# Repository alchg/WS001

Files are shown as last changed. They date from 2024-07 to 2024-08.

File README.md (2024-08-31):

# WS001  
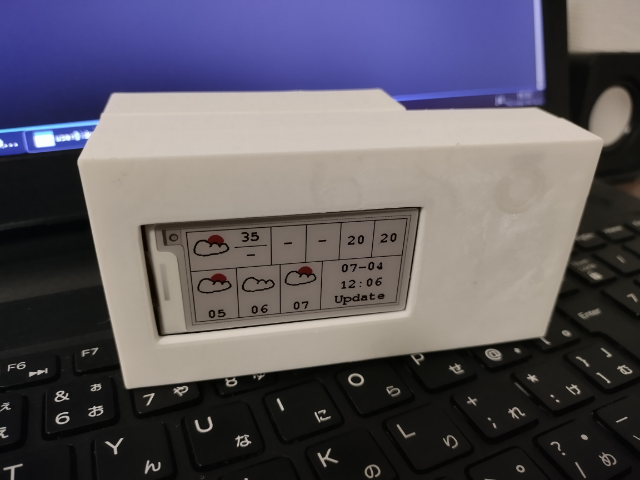
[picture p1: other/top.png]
Top Image
  
乾電池式電子ペーパーお天気ディスプレイのレポジトリです。  
作成マニュアルからプログラムやケースの３Ｄデータを含んでいます。  

# 仕様  
2.4Ghz WiFi（インターネットからの天気予報取得に必要）  
Bluetooth BLE（スマホから本機の初期設定する際に必要、LightBlueなどのBLE管理アプリが必要）  
気象庁の提供JSONデータによる全国天気予報表示  
一日４度の天気情報更新  
単３乾電池３本USB電源（有線USB電源も可能）  
連続動作３ヶ月以上（ニッケル水素充電池1950mAhによる）  

# 始め方  
最初のドキュメントは下記になります。  
ドキュメント\000はじめに.docx

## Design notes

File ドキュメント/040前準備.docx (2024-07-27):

Arduino IDEの準備（Arduino IDE 2.3.2を例とします）

- ボードマネージャーからesp32の2.0.6を導入します。

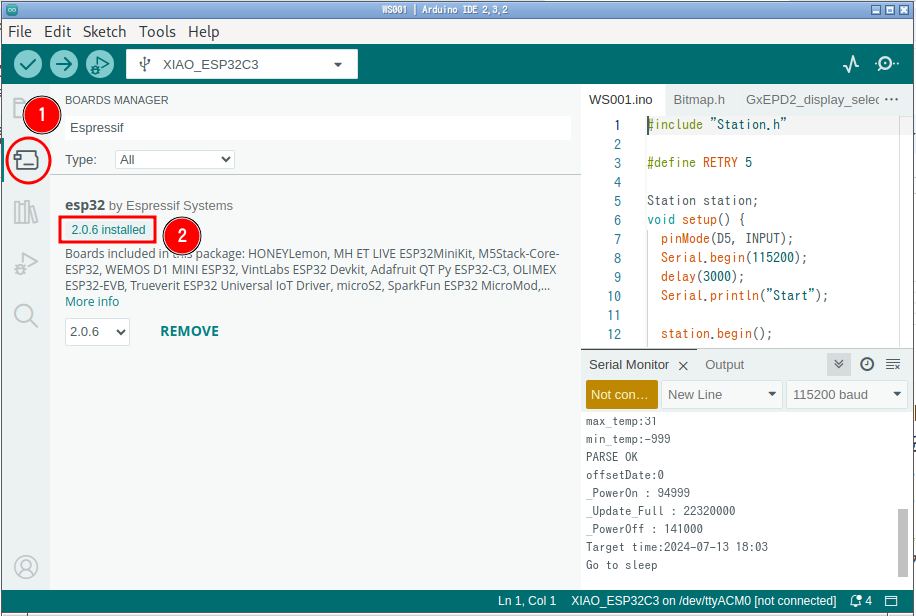
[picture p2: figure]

- ライブラリマネージャーからGxEPD2を導入します。

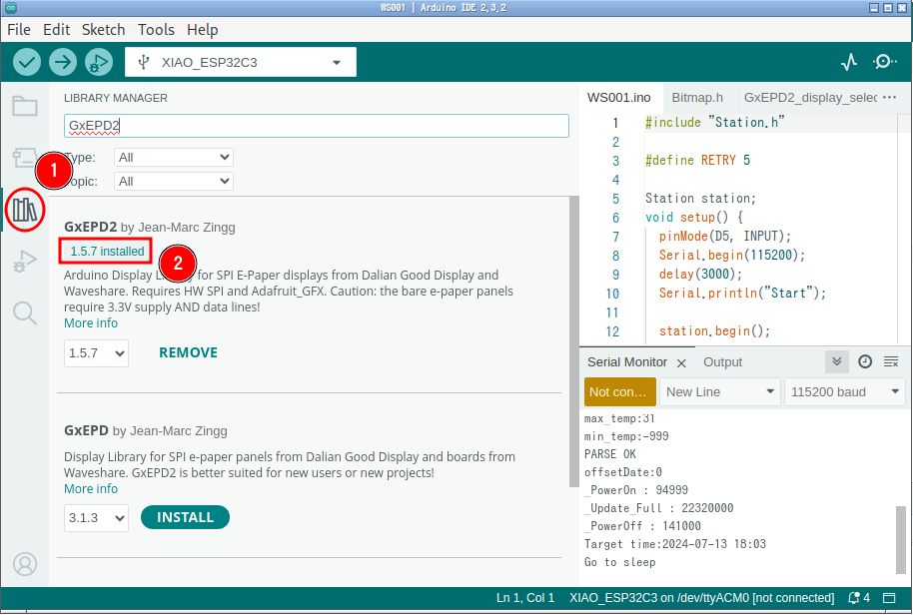
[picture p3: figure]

- ライブラリマネージャーからArduinoJsonを導入します。

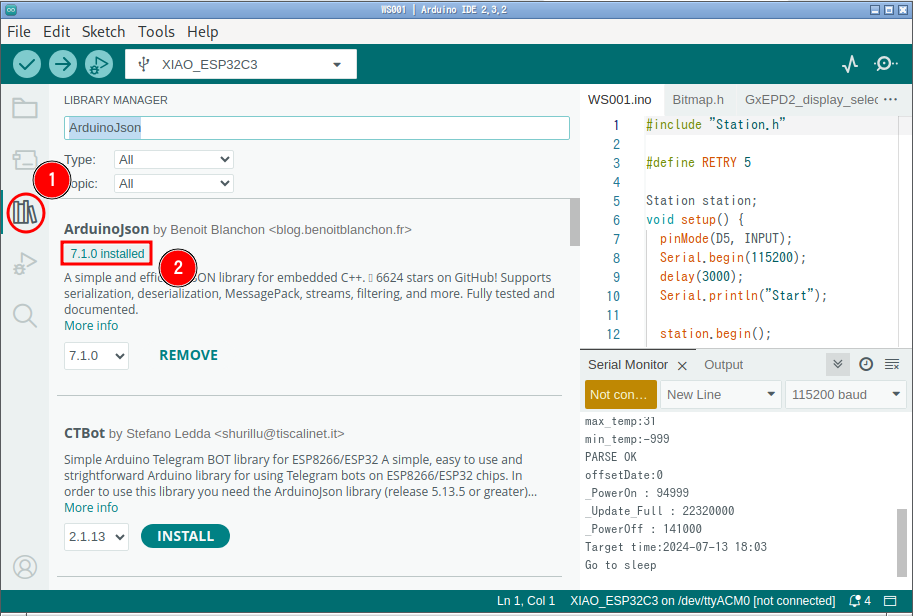
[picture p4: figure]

- プログラムのアップロードの設定は以下になります。赤枠を設定してください。

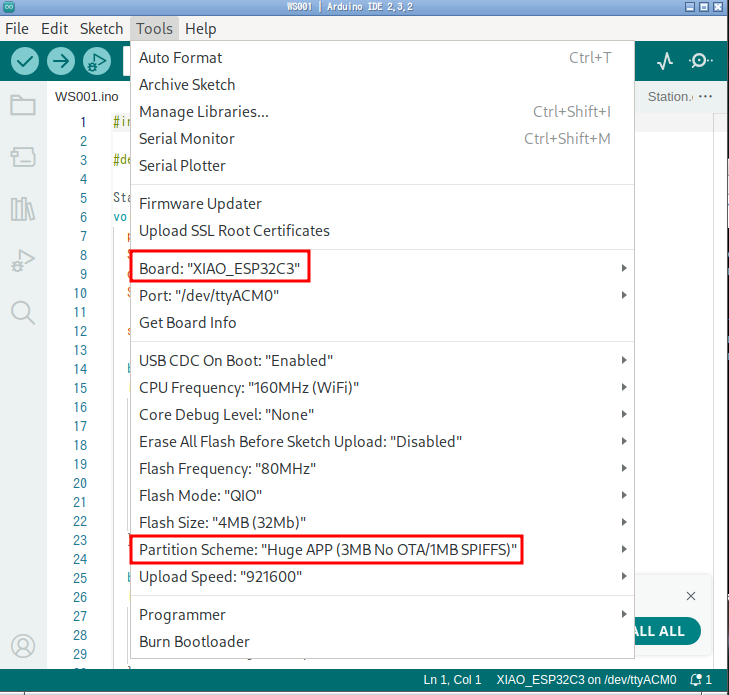
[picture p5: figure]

- この時点でXIAO ESP32 C3と接続して空プログラムのアップロードが可能であることを確認して置くことを推奨（Pythonやpyserialの導入や権限の設定など環境依存する場合があります）

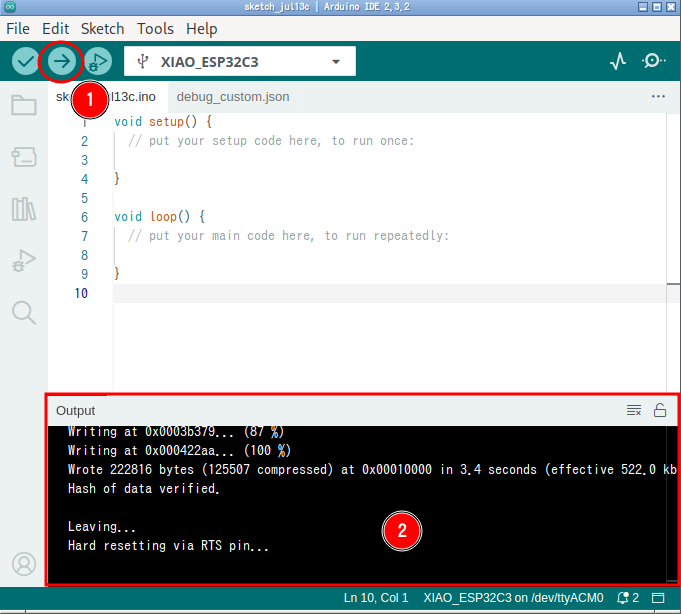
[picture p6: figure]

パーツの準備

- モジュールボックスと電池ボックスをセメダインABS用で接着します。配線用の穴の位置がずれないように注意して下さい。重しを乗せるかクランプ等で固定することを推奨します。（貼付け面に歪みが出ている場合は２つのパーツの貼り付け面を3Dプリンタのヒードベットで温めなおして押当てて調整することを推奨）

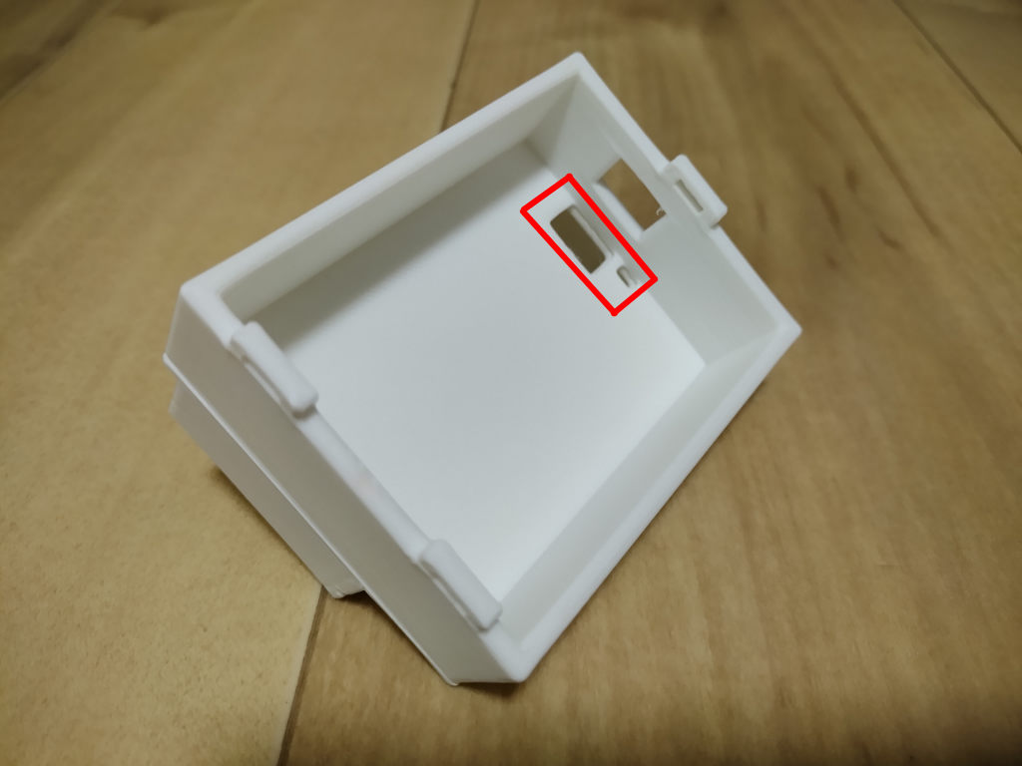
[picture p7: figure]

- Seeed Studio XIAO ESP32C3に7P×2のピンヘッダをハンダします。

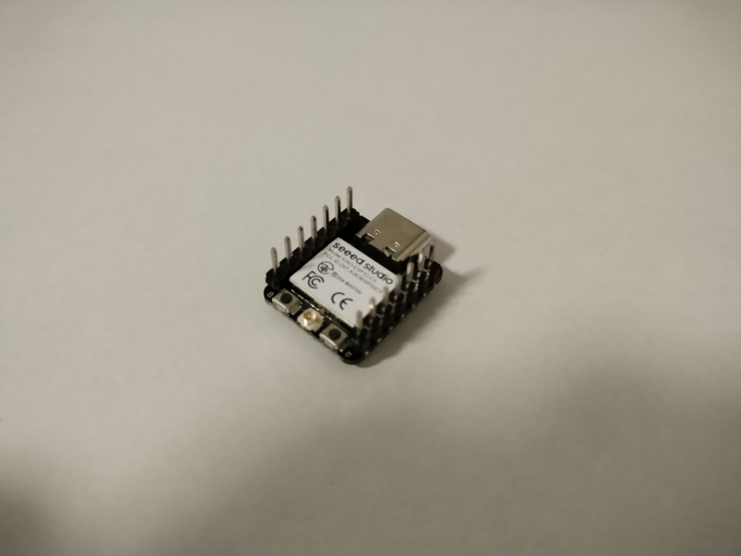
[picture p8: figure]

- TTP223に3P×1のピンヘッダをハンダします。

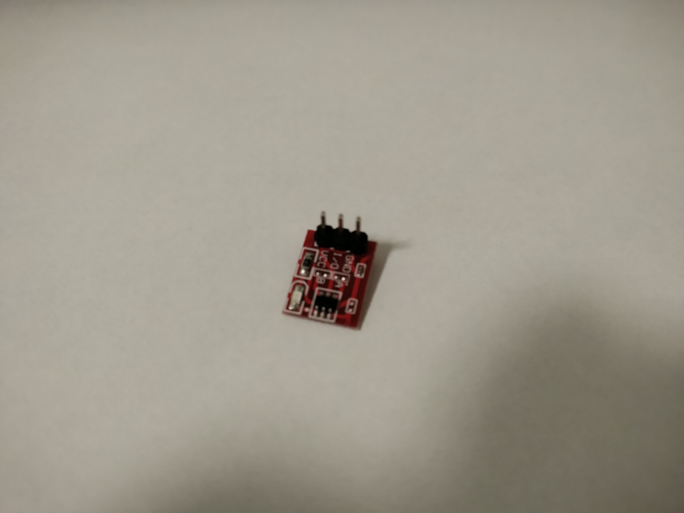
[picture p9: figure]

- MH-ET LIVE 2.13 REDに付属の真っ直ぐのピンヘッダをハンダします。

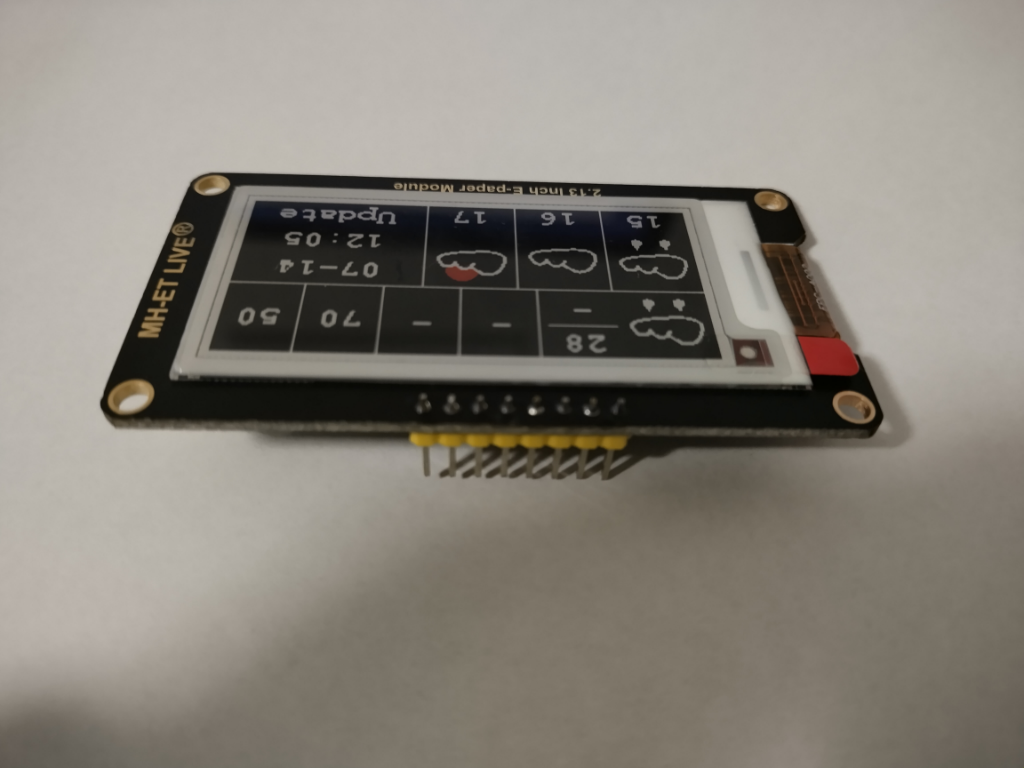
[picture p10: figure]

- 10cmと15cmメスーメスのジャンパピンを加工して分配ケーブルを作ります。ニッパー等で切断と被膜の除去を行い、絡めてハンダし、テープ等で絶縁処理します。赤と黒の２個作ります。

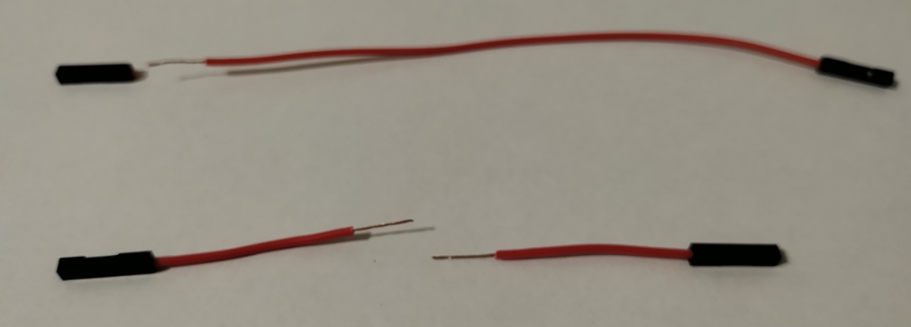
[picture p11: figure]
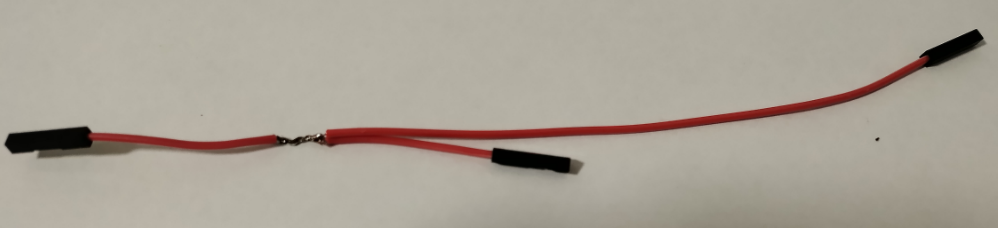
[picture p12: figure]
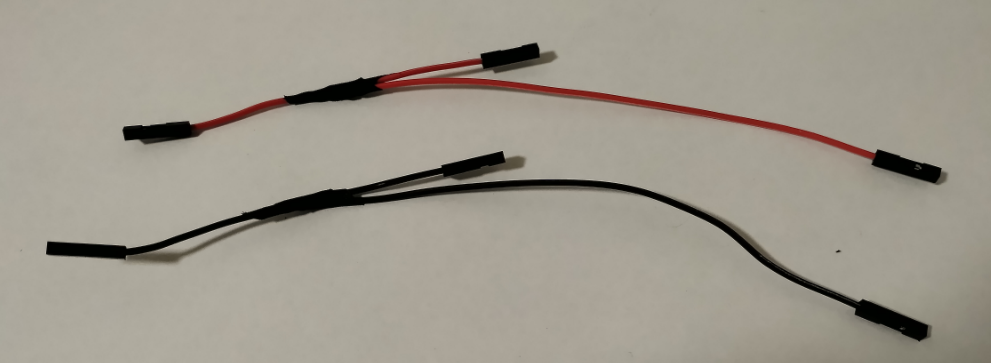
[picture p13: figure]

- 乾電池昇圧モジュールのLEDを除去します。LEDの両端を温めながらずらしていくと外せます。

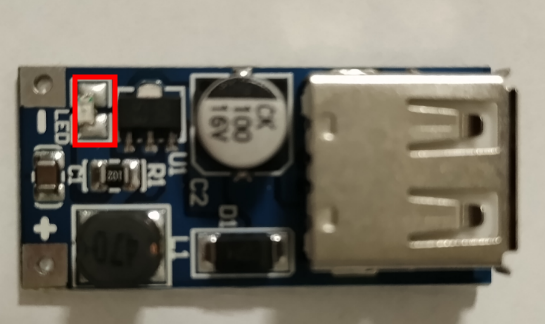
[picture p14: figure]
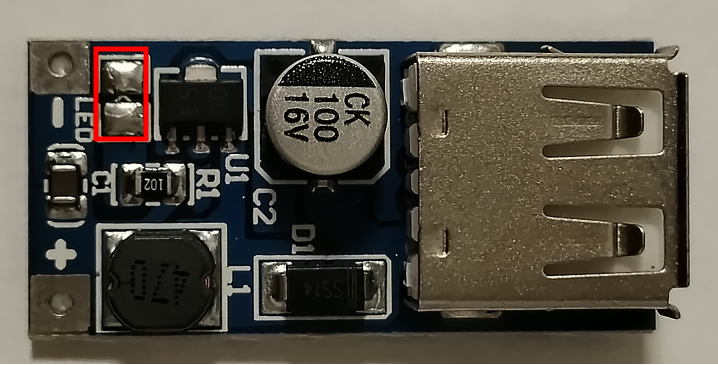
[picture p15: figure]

備考：必要な前準備は以上ですがブレッドボード等の電子パーツが既にある人は各部品の動作チェックを予め行っておくと良いでしょう。

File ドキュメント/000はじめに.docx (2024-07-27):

- はじめに

これはWS001-乾電池式電子ペーパーお天気ディスプレイのDIY向け手順書になります。

本プロジェクトは複雑な作業を減らすことを主要課題にしていますが、必要に応じてサーチエンジンによる情報検索等が必要になる場合があることを予め御了承願います。

機種依存になる3Dプリンタ印刷部分を除いた部分が、この組み立てマニュアルのメインパートになります。

3Dプリントに必要なモデルデータは本レポジトリに含まれることをここに明記しておきたいと思います。

また必要な手順や情報等は可能な限り含めていきますので続きのドキュメントを必要に応じてご覧ください。

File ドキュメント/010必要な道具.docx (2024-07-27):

必要な道具について記述します

- パソコンとUSB Type C通信ケーブル
  - 各種ソフトウェアを利用する為に必要です。ケーブルはファームウェアの書込みに使用します。
- スマートフォン（Bluetooth BLE）
  - WS001の初期設定にBluetooth BLE対応アプリの使用を必要とします。
- 3Dプリンタ及びその付属品
  - 熱溶解積層方式を想定しています。２万円台のプリンタで確認済みです。
- ニッパー
  - 電線の処理に使用します。ワイヤーストリッパーがある場合は推奨します。
- ビニールテープ
  - 絶縁処理に使用します。アセテート粘着テープがある場合は推奨します。
- はんだごてセット
  - ピンヘッダの接続などに使用します。複雑な事はしませんので安価な物で大丈夫ですが高性能品を使うと楽に作業できます。
- セメダインABS用
  - プラスチックパーツの接着に使用します。

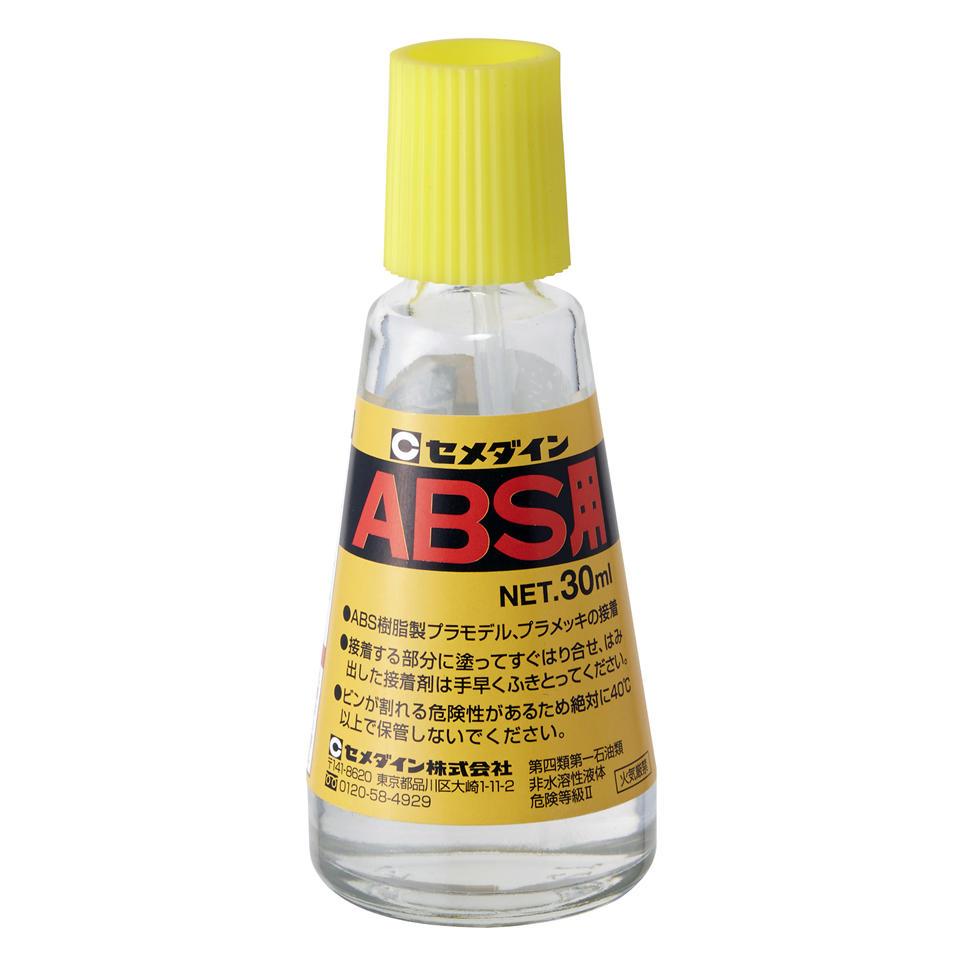
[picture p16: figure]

あると役に立つ可能性があるもの

- ルーター（電動工具）
  - ちょっとした加工やバリ取りなど幅広く活用できます。
- グルーガン
  - 固定に不安がある場合に活用できます。絶縁性もあります。
- クランプ
  - プラスチックパーツの接着など固定に活用できます。

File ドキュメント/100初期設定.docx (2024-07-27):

WS001の初期設定について記述します。Bluetooth BLE管理アプリが必要となります。例としてスマホアプリLightBlueを用いて記述します。

- 初回起動時、または電源ONから３秒以内に右上をタッチし続けると設定モードになります。

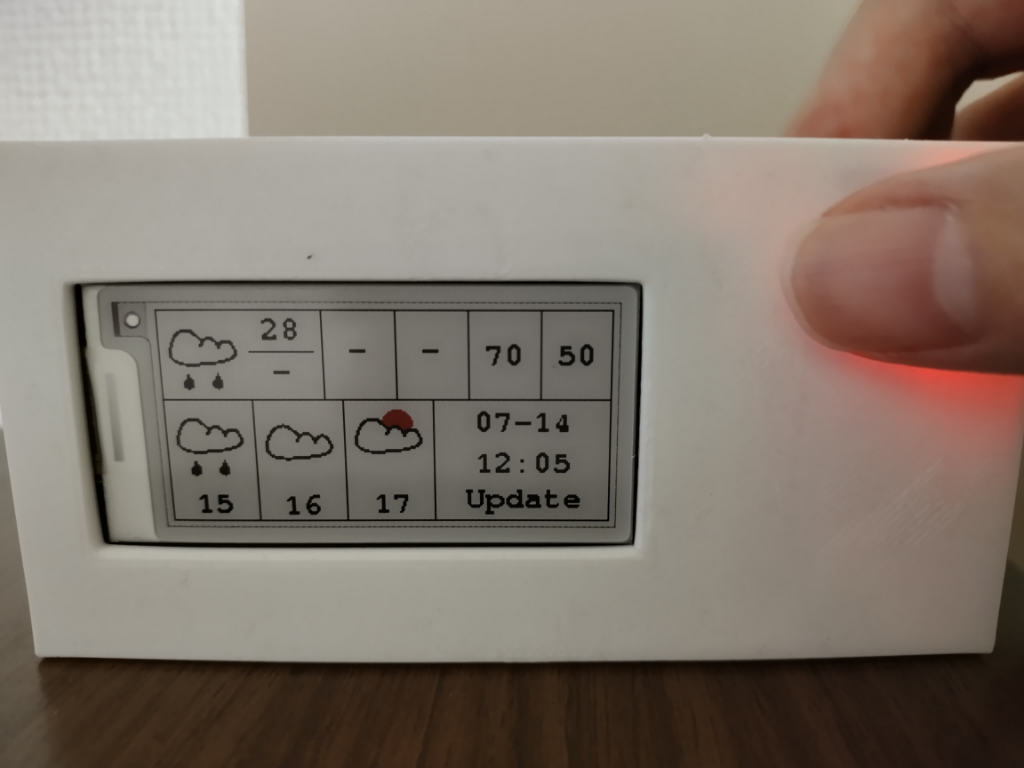
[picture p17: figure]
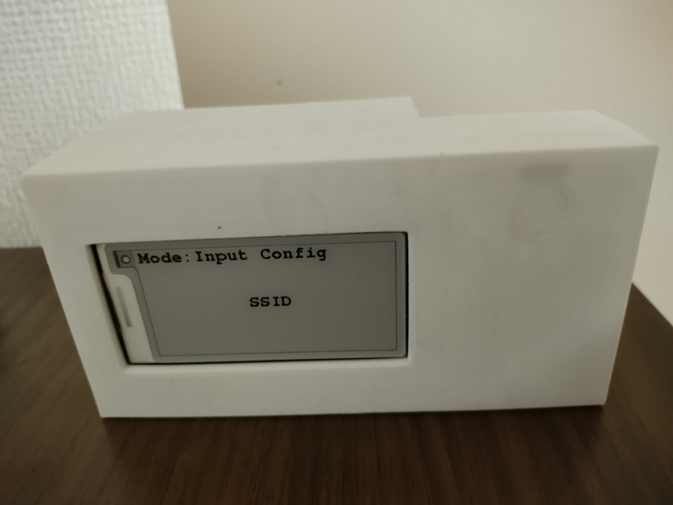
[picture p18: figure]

- スマホアプリLightBlueでWS001に接続します。

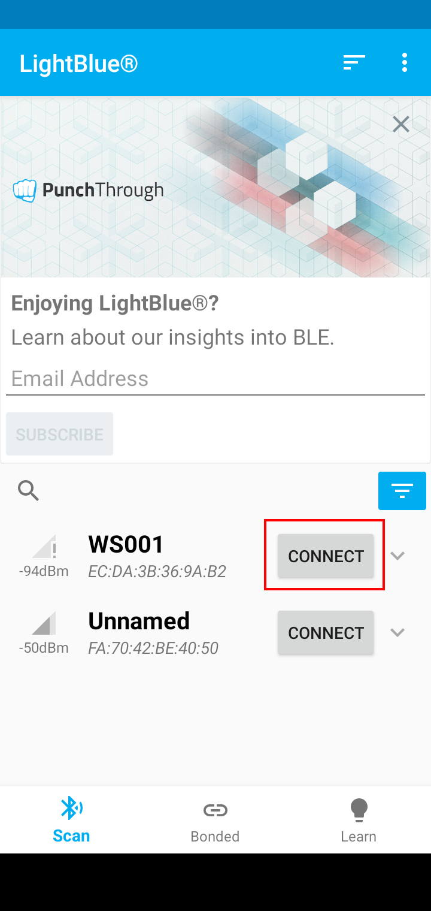
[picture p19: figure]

- WritableのUUIDを選択します。

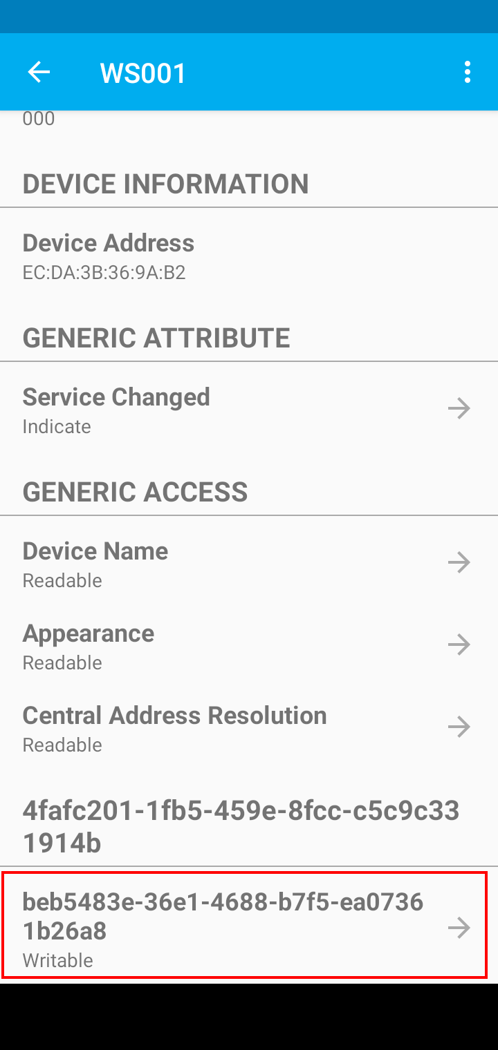
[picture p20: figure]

- UTF-8 Stringを選択してテキストを入力後にWRITEを選択するとデータを送信できます。最初はSSIDとパスワードを設定します。WS001の画面に従い設定して下さい。

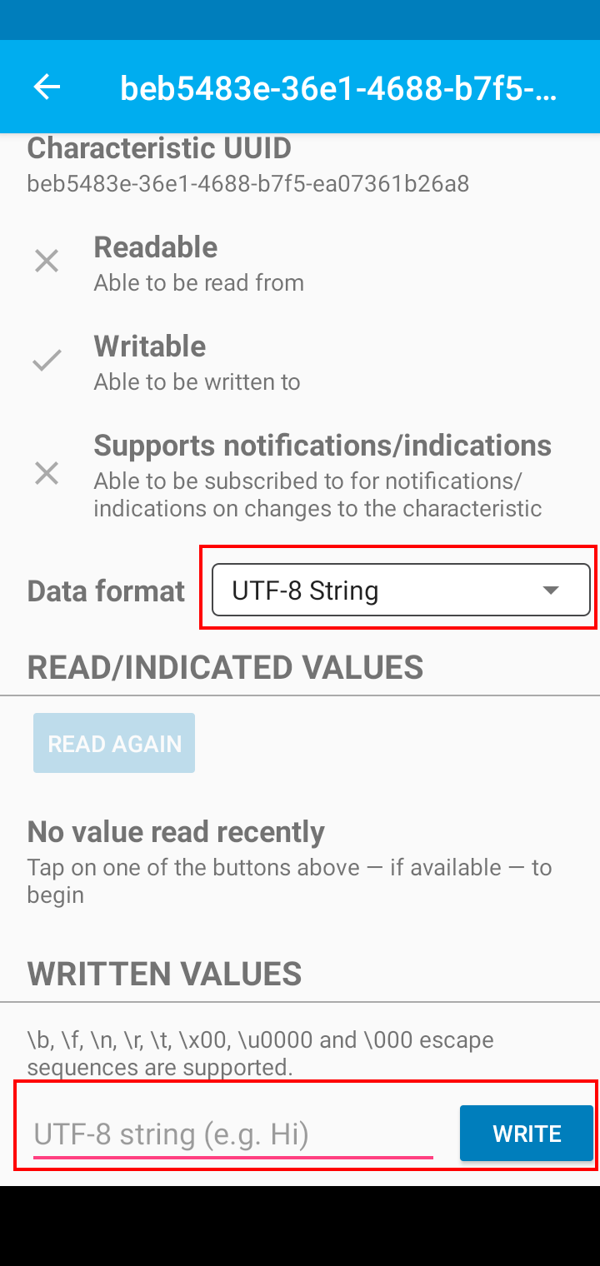
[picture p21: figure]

- WS001の画面に従い、前述の方法でエリアコードを設定していきます。101エリアコードから１行を選択し設定して下さい。
- 最後にダークモードを設定します。0で通常モード、1でダークモードです。

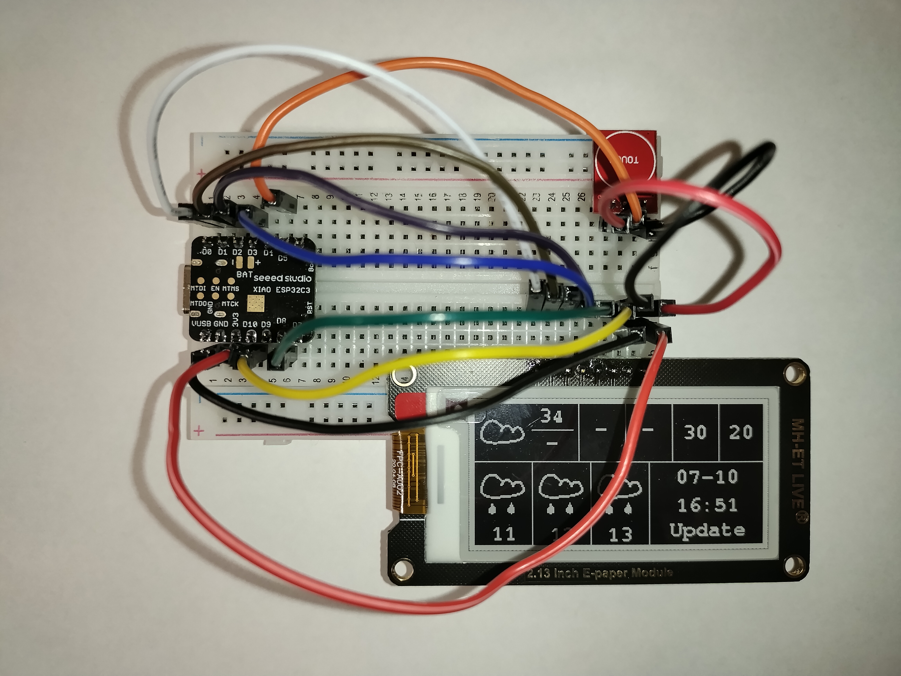
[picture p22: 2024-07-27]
ドキュメント/031配線図１.jpg

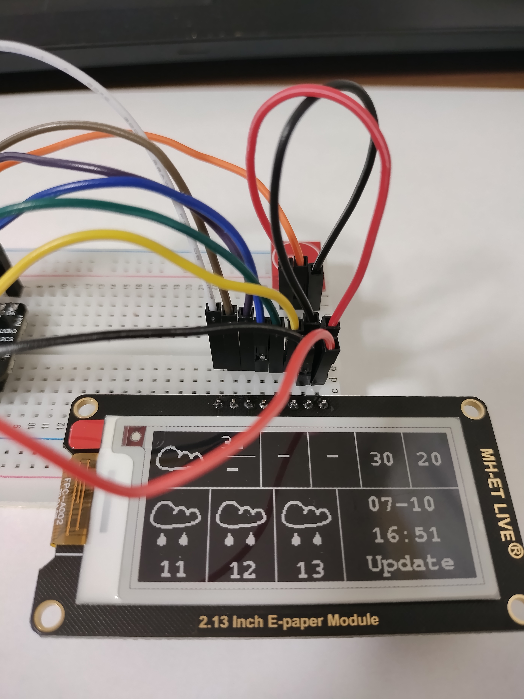
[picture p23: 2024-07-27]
ドキュメント/033配線図３.jpg

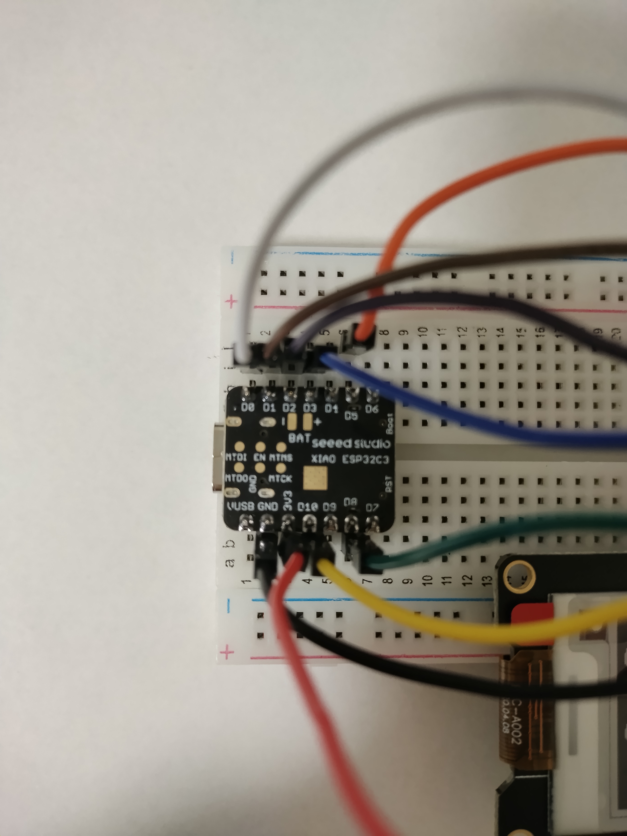
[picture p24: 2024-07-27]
ドキュメント/032配線図２.jpg

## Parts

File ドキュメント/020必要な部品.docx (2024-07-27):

必要な部品について記述します

- Seeed Studio XIAO ESP32C3
  - 本体のマイコンです。スイッチサイエンス等で購入可能です。
- タッチスイッチ TTP223
  - 設定モードを使用する為のスイッチです。Amazon等で購入可能です。
- ピンヘッダ40P
  - 実際に使用するのは7P×2、3P×1です。マイコンとスイッチに使用します。

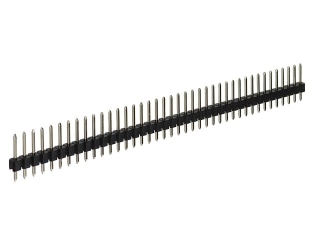
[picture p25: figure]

- 2.13 epaper module [MH-ET LIVE 2.13 RED]
  - 白黒赤3色の電子ペーパーディスプレイです。AliExpressで購入可能です。メルカリでも販売しているようです。

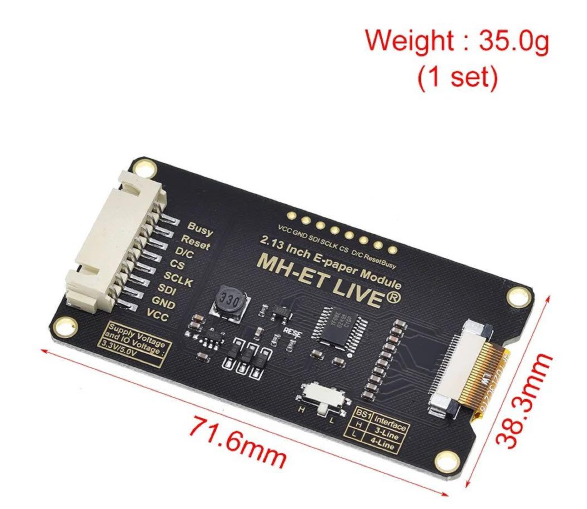
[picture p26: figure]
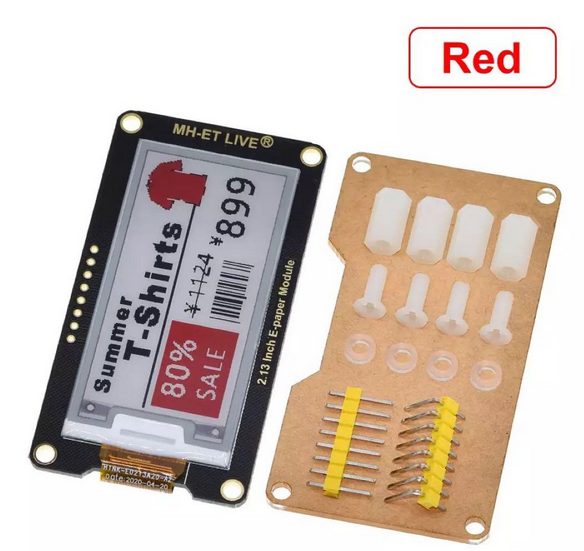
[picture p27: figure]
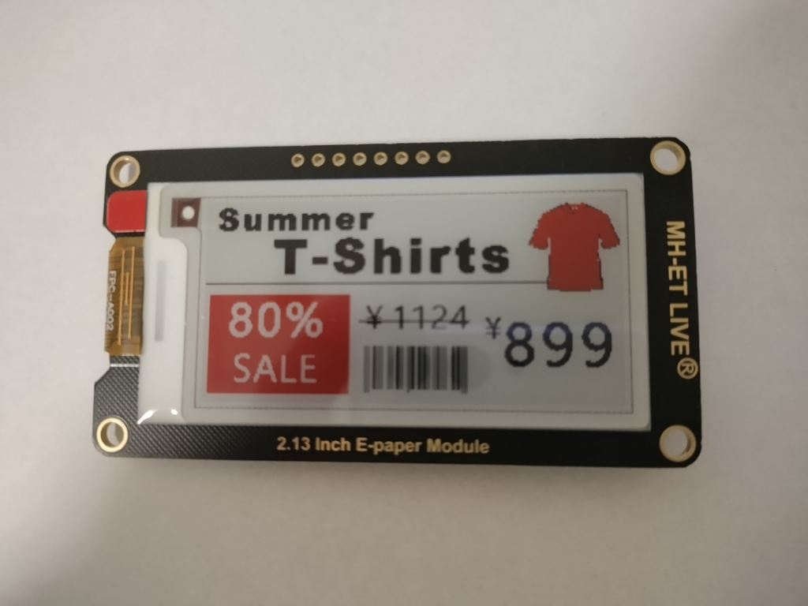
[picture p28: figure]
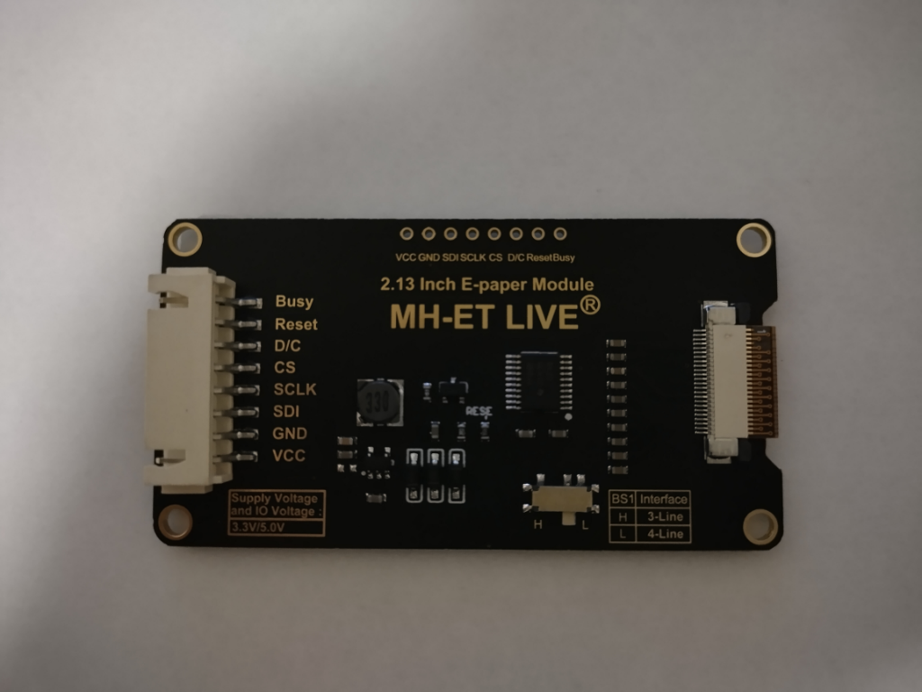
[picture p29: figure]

- 15cmメスーメスのジャンパピン40本
  - 実際に使用するのは8本です。セット売りが基本なので予備も兼ねてのこの本数です。際どいですが20cmでも対応可能です。
- 10cmメスーメスのジャンパピン40本
  - 実際に使用するのは3本です。セット売りが基本なので予備も兼ねてのこの本数です。
- 乾電池昇圧モジュール（USB 5V出力）
  - 電池の昇圧に使用します。Amazonで購入可能です。https://www.amazon.co.jp/dp/B01N0AF6YJ

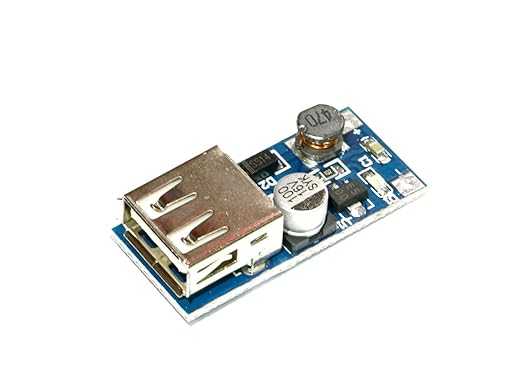
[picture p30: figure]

- USBケーブルAオスーCオス20cm程度以上
  - 乾電池昇圧モジュールに接続します。（下記画像はセリアの物ですmicroUSBは不要なので切断します）

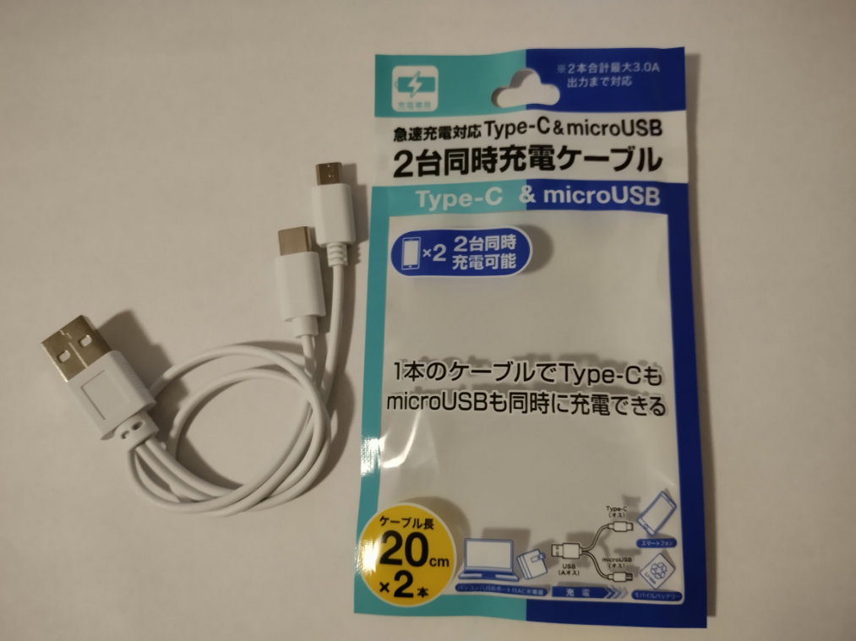
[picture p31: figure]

- 単3×3電池ボックスAP-133
  - 乾電池昇圧モジュールに接続します。ヨドバシ.com等で購入可能です。

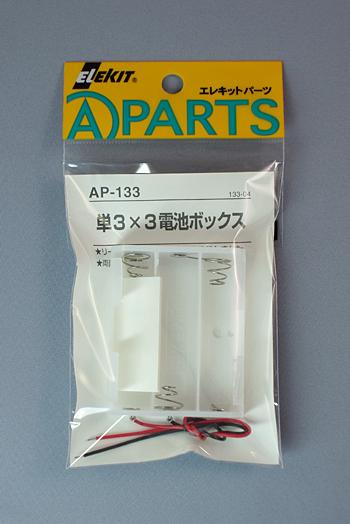
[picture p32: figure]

- 結束バンド（小）
  - USBケーブルを固定します。
- フロントパネル（FrontPanel.3mf）


- バックパネル（BackPanel.3mf）


- ディスプレイ固定具（DisplayFix.3mf）


- スイッチ固定具（SwitchFix.3mf）


- モジュールボックス（BatteryModule.3mf）


- モジュールボックス蓋（BatteryModuleLid.3mf）


- 電池ボックス（BatteryBox.3mf）


- 電池ボックス蓋（BatteryBoxLid.3mf）


備考：3Dプリント品は各部品を組み立てて精度チェックを実施しておく事を推奨します。

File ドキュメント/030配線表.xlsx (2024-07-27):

MH-ET LIVE 2.13 RED
ピン名 | 接続先 | 備考
D0 | Busy
D1 | Reset
D2 | D/C
D3 | CS
D8 | SCLK | SCK
D10 | SDI | MOSI
3V3 | VCC
GND | GND
TTP223
ピン名 | 接続先 | 備考
D5 | I/O
3V3 | VCC
GND | GND

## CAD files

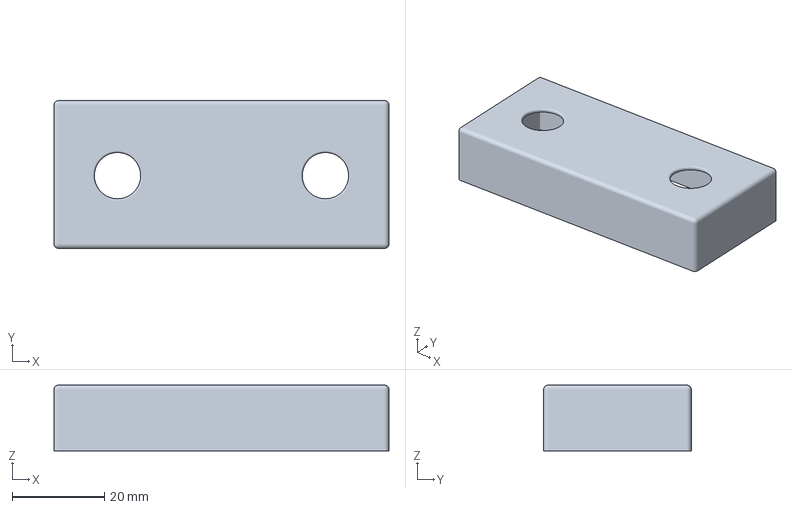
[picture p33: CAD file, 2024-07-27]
ケース３Ｄモデル/BatteryModuleLid.3mf
72.5 x 32.0 x 14.2 mm

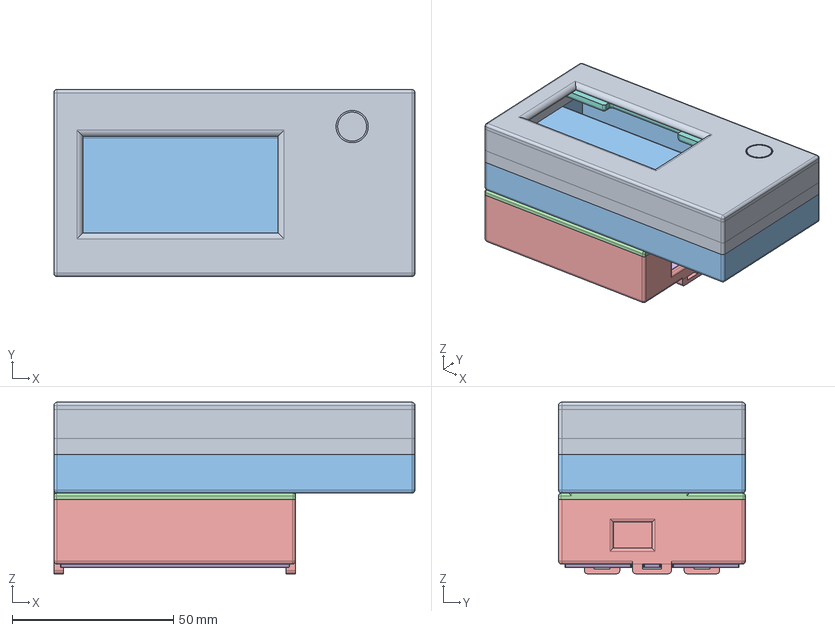
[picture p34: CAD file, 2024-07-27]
ケース３Ｄモデル/FreeCAD/WS001.FCStd
112.0 x 58.0 x 53.3 mm
FrontPanel
SwitchFix
BackPanel
BatteryModule
BatteryBox
BatteryBoxLid
BatteryModuleLid
DisplayFix

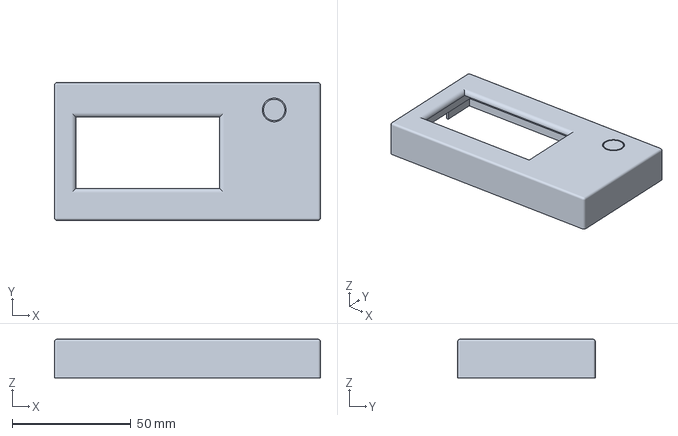
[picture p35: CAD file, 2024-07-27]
ケース３Ｄモデル/FrontPanel.3mf
112.0 x 58.0 x 16.2 mm

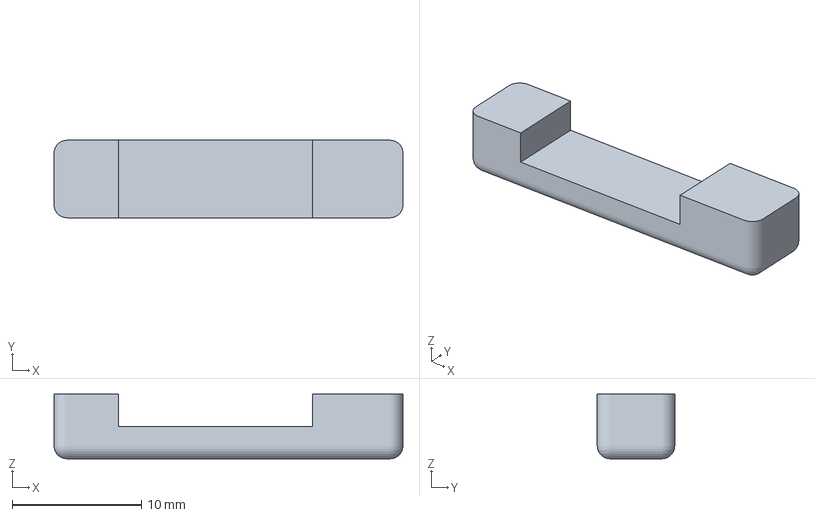
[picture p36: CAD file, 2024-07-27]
ケース３Ｄモデル/SwitchFix.3mf
27.0 x 6.00 x 5.00 mm

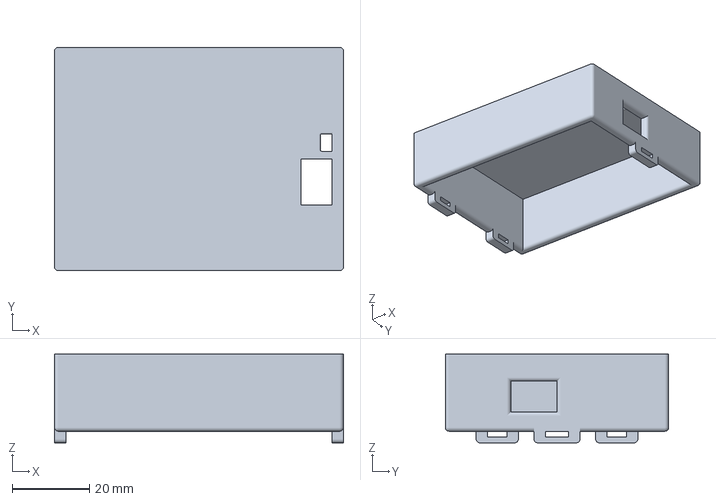
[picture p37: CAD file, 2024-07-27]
ケース３Ｄモデル/BatteryBox.3mf
75.0 x 58.0 x 23.0 mm

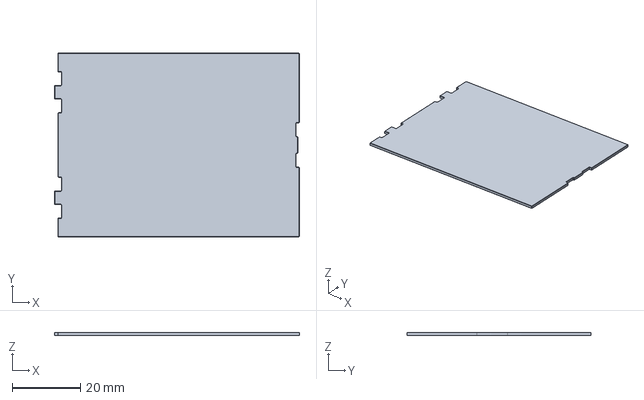
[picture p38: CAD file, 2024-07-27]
ケース３Ｄモデル/BatteryBoxLid.3mf
72.0 x 54.0 x 1.00 mm

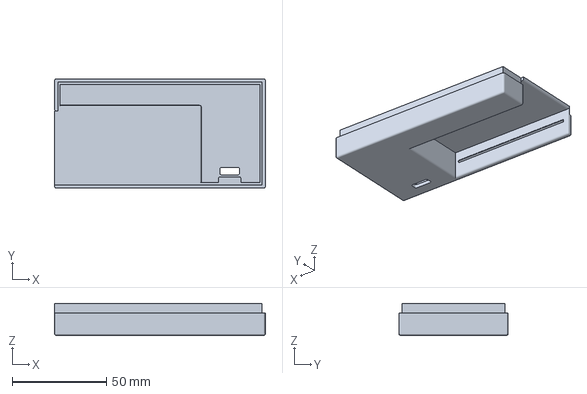
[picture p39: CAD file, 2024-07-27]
ケース３Ｄモデル/BackPanel.3mf
112.0 x 58.0 x 17.0 mm

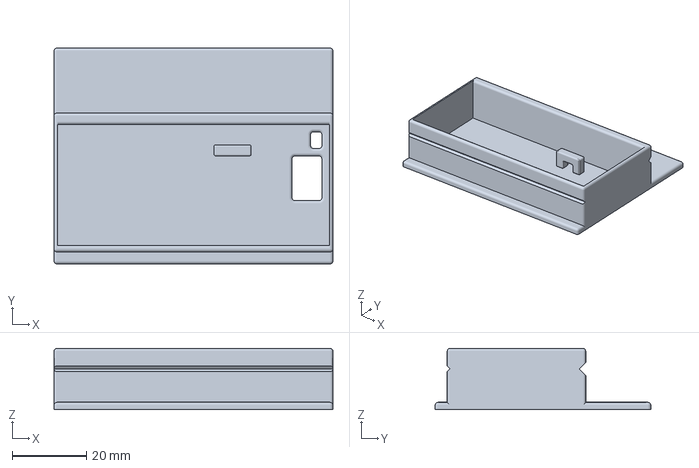
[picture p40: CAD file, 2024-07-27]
ケース３Ｄモデル/BatteryModule.3mf
75.0 x 58.0 x 16.5 mm

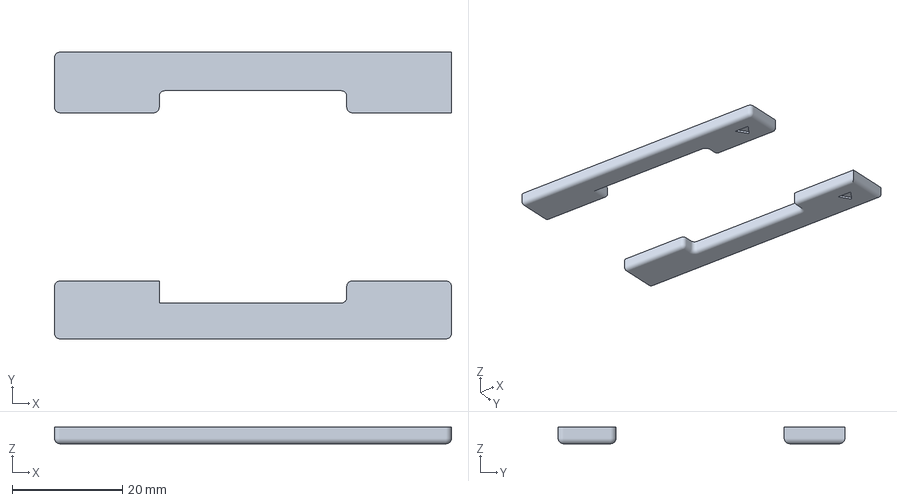
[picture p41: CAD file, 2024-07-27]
ケース３Ｄモデル/DisplayFix.3mf
72.0 x 52.0 x 3.00 mm

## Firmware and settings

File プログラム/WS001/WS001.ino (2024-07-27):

#include "Station.h"

#define RETRY 5

Station station;
void setup() {
  pinMode(D5, INPUT);
  Serial.begin(115200);
  delay(3000);
  Serial.println("Start");

  station.begin();

  bool enableSetConfig = false;
  if(digitalRead(D5) == HIGH){
    delay(1000);
    if(digitalRead(D5) == HIGH){
      delay(1000);
      if(digitalRead(D5) == HIGH){
        enableSetConfig = true;
      }
    }
  }

  bool enableSaveConfig = false;
  if(enableSetConfig || station.loadConfig() == false){
    Serial.println("SetConfig");
    station.getConfig();
    enableSaveConfig = true;
  }

  if(enableSaveConfig){
    Serial.println("SaveConfig");
    if(station.saveConfig() == false){
      station.dispError("SAVE CONFIG ERROR");
      Serial.println("SaveConfig ERR");
    }
  }

  station.setColorMode();

  bool enableWLAN = false;
  for(int i=0;i < RETRY;i++){
    if(station.tryWLAN()){
      enableWLAN = true;
      Serial.println("WLAN OK");
      break;
    }else{
      Serial.println("WLAN ERR");
      delay(1000);
      if(i == RETRY - 1){
        station.dispError("WLAN ERROR");
      }
    }
  }

  bool enableNTP = false;
  if(enableWLAN){
    for(int i=0;i < RETRY;i++){
      if(station.tryNTP()){
        enableNTP = true;
        Serial.println("NTP OK");
        break;
      }else{
        Serial.println("NTP ERR");
        delay(1000);
        if(i == RETRY - 1){
          station.dispError("NTP ERROR");
        }
      }
    }
  }

  bool enableJSON = false;
  if(enableNTP){
    for(int i=0;i < RETRY;i++){
      if(station.getWeather()){
        enableJSON = true;
        Serial.println("GET OK");
        break;
      }else{
        Serial.println("GET ERR");
        delay(1000);
        if(i == RETRY - 1){
          station.dispError("HTTP ERROR");
        }
      }
    }
  }

  station.disconnectWLAN();

  bool enableParse = false;
  if(enableJSON){
    if(station.parseWeather()){
      enableParse = true;
      Serial.println("PARSE OK");
    }else{
      station.dispError("DATA ERROR");
      Serial.println("PARSE ERR");
    }
  }

  if(enableParse){
    station.dispWeather();
  }

  station.sleep(enableParse);
}

void loop() {}

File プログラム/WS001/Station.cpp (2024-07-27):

#include "Station.h"
#include <ArduinoJson.h>
#include <SPIFFS.h>
#include <WiFi.h>
#include <HTTPClient.h>
#include <WiFiClientSecure.h>
#include <GxEPD2_3C.h>
#include "GxEPD2_display_selection_new_style.h"
#include <Fonts/FreeMonoBold9pt7b.h>
#include "Bitmap.h"

Station::Station(){
}

void Station::begin(){

  display.init(115200, true, 2, false); // 115200 to 0 false serial
  display.setRotation(3);
  display.setFont(&FreeMonoBold9pt7b);
  SPIFFS.begin(true);
  front_color = GxEPD_BLACK;
  back_color = GxEPD_WHITE;
  display.setTextColor(front_color);

}

void Station::getConfig(){
  ServerBLE svr;
  svr.begin();
}

bool Station::loadConfig(){

  if(!SPIFFS.exists(CONFIG_FILE)){
    Serial.println("Config File Not Found");
    return false;
  }
  File configFile = SPIFFS.open(CONFIG_FILE, "r");
  size_t size = configFile.size();
  std::unique_ptr<char[]> buf(new char[size]);
  configFile.readBytes(buf.get(), size);
  configFile.close();

  DynamicJsonDocument doc(200);
  DeserializationError error = deserializeJson(doc, buf.get());
  if(error){
    Serial.println("DeserializationError");
    return false;
  }

  dark_mode = doc["dark_mode"];
  strncpy(ssid, doc["ssid"],99);
  strncpy(password, doc["password"],99);
  strncpy(area_code, doc["area_code"],99);
  strncpy(area_code_sub, doc["area_code_sub"],99);
  strncpy(spot_code, doc["spot_code"],99);
  strncpy(area_code_week, doc["area_code_week"],99);

  return true;
}

bool Station::saveConfig(){

  File configFile = SPIFFS.open(CONFIG_FILE, "w");
  if (!configFile) {
    return false;
  }

  DynamicJsonDocument doc(200);
  doc["dark_mode"] = dark_mode;
  doc["ssid"] = ssid;
  doc["password"] = password;
  doc["area_code"] = area_code;
  doc["area_code_sub"] = area_code_sub;
  doc["spot_code"] = spot_code;
  doc["area_code_week"] = area_code_week;

  if(serializeJson(doc, configFile) == 0){
    configFile.close();
    return false;
  }
  configFile.close();

  return true;
}

void Station::setColorMode(){
  if(dark_mode){
    front_color = GxEPD_WHITE;
    back_color = GxEPD_BLACK;
  }else{
    front_color = GxEPD_BLACK;
    back_color = GxEPD_WHITE;
  }
  display.setTextColor(front_color);
}

bool Station::tryWLAN(){
  bool ret = false;

  WiFi.begin(ssid, password);
  for(int i=0;i<10;i++){
    delay(1000);
    if(WiFi.status() == WL_CONNECTED){
      ret = true;
      break;
    }
  }

  return ret;
}

bool Station::tryNTP(){
  bool ret = false;

  configTime(60 * 60 * 9, 0, "ntp.jst.mfeed.ad.jp", "ntp.nict.jp");
  time_t nowSecs = time(nullptr);
  for(int i=0;i < 30;i++){
    if(nowSecs > 60 * 60 * 24 * 365 * 10){
      ret = true;
      break;
    }
    delay(1000);
    nowSecs = time(nullptr);
  }

  return ret;
}

bool Station::getWeather(){
  bool ret = false;

  WiFiClientSecure *client = new WiFiClientSecure;
  if(client) {
    client -> setCACert(rootCACertificate);
    {
      HTTPClient https;
      String url = "https://www.jma.go.jp/bosai/forecast/data/forecast/";
      url += area_code;
      url += ".json";
      if(https.begin(*client, url)){
        int httpCode = https.GET();
        if (httpCode == HTTP_CODE_OK){
          payload = https.getString();
          ret = true;
        }else{
          Serial.printf("[HTTPS] GET... failed, error: %s\n", https.errorToString(httpCode).c_str());
        }
        https.end();
      } else {
        Serial.printf("[HTTPS] Unable to connect\n");
      }
    }
    delete client;
  }
  
  return ret;
}

void Station::disconnectWLAN(){
  WiFi.disconnect();
  WiFi.mode(WIFI_OFF);
}

bool Station::parseWeather(){
  StaticJsonDocument<200> doc;
  struct tm timeinfo;
  getLocalTime(&timeinfo);
  String localDate = String(timeinfo.tm_year + 1900) + "-" + (timeinfo.tm_mon + 1 < 10 ? "0" : "") + String(timeinfo.tm_mon + 1) + "-" + (timeinfo.tm_mday < 10 ? "0" : "") + String(timeinfo.tm_mday);
  Serial.println("localDate      :" + localDate);
  
  DeserializationError error = deserializeJson(doc, payload);
  if(error){
    Serial.println("Deserialization error.");
    return false;
  }else{
    String tmpTimeDefine = "";
    int idxTodayDefWeatherCode;
    for(int i=0;i < doc[0]["timeSeries"][0]["timeDefines"].size();i++){
      tmpTimeDefine = doc[0]["timeSeries"][0]["timeDefines"][i].as<String>().substring(0,10);
      if(tmpTimeDefine == localDate){
        idxTodayDefWeatherCode = i;
        Serial.println("idxTodayDefWeatherCode:" + String(idxTodayDefWeatherCode));
        break;
      }
    }

    bool noWeatherCodes = true;
    for (const auto& area : doc[0]["timeSeries"][0]["areas"].as<JsonArray>()) {
      if (area["area"]["code"] == area_code_sub) {
        JsonArray weatherCodes = area["weatherCodes"];
        weather_info.code = weatherCodes[idxTodayDefWeatherCode];
        noWeatherCodes = false;
        Serial.println("code:" + String(weather_info.code));
        break;
      }
    }
    if(noWeatherCodes){
      return false;
    }

    int idx_area_sub = NO_DATA;
    for(int i=0;i < doc[0]["timeSeries"][1]["areas"].size();i++){
      if(doc[0]["timeSeries"][1]["areas"][i]["area"]["code"].as<String>() == area_code_sub){
        idx_area_sub = i;
        break;
      }
    }
    Serial.println("idx_area_sub:" + String(idx_area_sub));
    if(idx_area_sub == NO_DATA){
      return false;
    }

    for(int i=0;i < 4;i++){
      weather_info.pops[i] = NO_DATA;
    }
    for(int i=0;i < doc[0]["timeSeries"][1]["timeDefines"].size();i++){
      String tmpPopDate = doc[0]["timeSeries"][1]["timeDefines"][i].as<String>().substring(0,13);
      //Serial.println(tmpPopDate);
      if(idx_area_sub != NO_DATA){
        int tmpPop = doc[0]["timeSeries"][1]["areas"][idx_area_sub]["pops"][i].as<int>();
        if(tmpPopDate == localDate + "T00"){
          weather_info.pops[0] = tmpPop;
          //Serial.println("T00:" + String(weather_info.pops[0]));
        }
        if(tmpPopDate == localDate + "T06"){
          weather_info.pops[1] = tmpPop;
          //Serial.println("T06:" + String(weather_info.pops[1]));
        }
        if(tmpPopDate == localDate + "T12"){
          weather_info.pops[2] = tmpPop;
          //Serial.println("T12:" + String(weather_info.pops[2]));
        }
        if(tmpPopDate == localDate + "T18"){
          weather_info.pops[3] = tmpPop;
          //Serial.println("T18:" + String(weather_info.pops[3]));
        }
      }
    }

    weather_info.max_temp = NO_DATA;
    weather_info.min_temp = NO_DATA;
    int idxTodayDefTemp[2];
    bool enableTemp = false;
    for (int i=0;i < doc[0]["timeSeries"][2]["timeDefines"].size();i++){
      String tmpTempDate = doc[0]["timeSeries"][2]["timeDefines"][i].as<String>().substring(0, 10);
      //Serial.println(tmpTempDate);
      if(localDate == tmpTempDate){
        idxTodayDefTemp[i] = i;
        enableTemp = true;
        Serial.println("idxTodayDefTemp[" + String(i) + "]:" + String(idxTodayDefTemp[i]));
      }
    }
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

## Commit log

2024-07-04 仕様追記
2024-07-04 改行修正
2024-07-27 ファイル追加
    [030配線表.xlsx, 101エリアコード.xlsx, BackPanel.3mf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]
2024-07-27 解説等の修正
2024-08-31 公開向けの修正
2025-02-26 ルート証明書の修正
